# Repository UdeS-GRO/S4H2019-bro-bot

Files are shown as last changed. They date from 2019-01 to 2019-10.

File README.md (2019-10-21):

# bro-bot
<pre>
 ______     ______     ______     ______     ______     ______  
/\  == \   /\  == \   /\  __ \   /\  == \   /\  __ \   /\__  _\ 
\ \  __<   \ \  __<   \ \ \/\ \  \ \  __<   \ \ \/\ \  \/_/\ \/ 
 \ \_____\  \ \_\ \_\  \ \_____\  \ \_____\  \ \_____\    \ \_\ 
  \/_____/   \/_/ /_/   \/_____/   \/_____/   \/_____/     \/_/ 
 </pre>
Welcome to our college robotic project. We are the Bro-bot team and for a our session project we had to make an open source robotic project.

The Bro-Bot is a 3 degrees of freedom robot arm with a gripper at its end. The robot has 3 different control sytems: joint-directly controlled, cartesian teach controlled and impedance controlled. The grimper, on the other hand, is controlled by a wireless glove with flex sensors (inspired by a youtube project https://www.youtube.com/watch?v=uEd2B7fS8Eg&t=777s).

The team: 
We are at Université de Sherbrooke in the robotic engineering program. The team is composed of Tristan Dumais, Philippe Doucerain, Jean-Michel Lemaire, Maxime Lamoureux, Marc-André Martel and Étienne Villemure

## Start the project 
All materials to be acquired and all the necessary softwares to download can be found in this Github wiki in the section **Getting started!!**

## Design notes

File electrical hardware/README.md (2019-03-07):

# Electrical hardware

This section contains all the circuits in the project (except commercial PCB),

Some circuits is in a .fzz format. You will need to install the free sofware **Fritzing** to read/edit it. The installation procedure can be found in the [Wiki section](https://github.com/tdumais23/bro-bot/wiki/Getting-Started!).

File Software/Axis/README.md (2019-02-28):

# Axis class

The axis class contains all the necessary methods and attributes to use each dynamixel motors.

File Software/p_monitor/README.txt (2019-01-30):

The library p_monitor.h is a derived version of the p_monitor OpenCr example in the arduino IDE. You should read the p_monitor.cpp before 
using it to be aware of its license. 

This library is used to symplify the way of sending commands to the Dynamixel motors. If you want to use our main_opencr program, you
should copy this directory inside your /Arduino/libraries. In Windows it should be in C:\Users\user\Documents\Arduino\libraries.

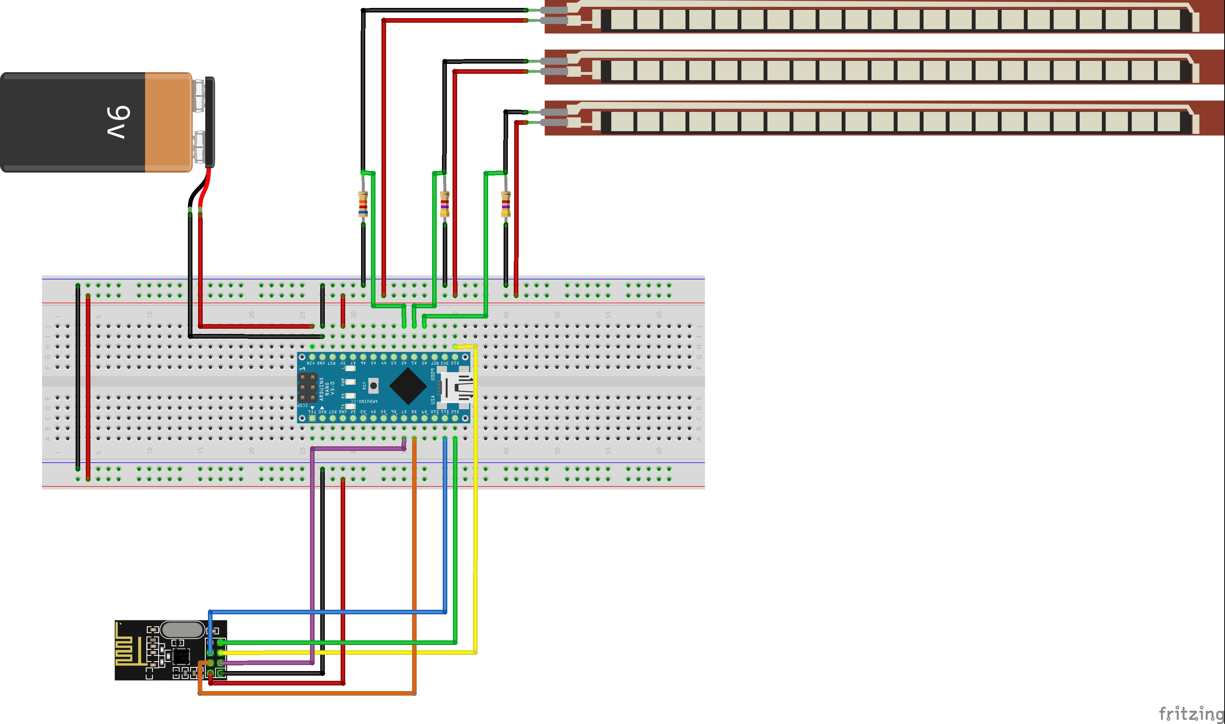
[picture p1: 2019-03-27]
electrical hardware/transceiver_gloveV2_bb.jpg

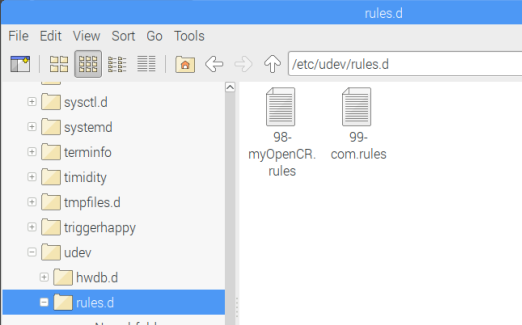
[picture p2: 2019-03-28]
finalUdevPicture.PNG

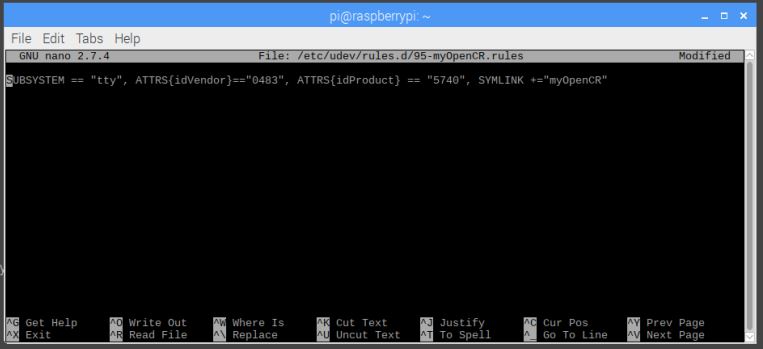
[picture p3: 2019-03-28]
UdevWiki.JPG

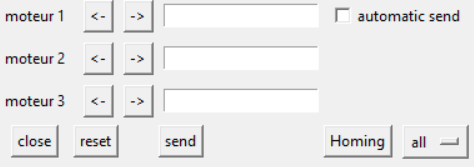
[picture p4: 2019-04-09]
image_wiki/moteur_control.PNG

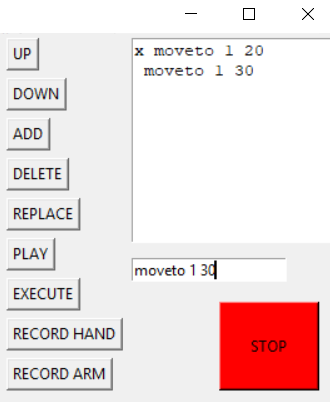
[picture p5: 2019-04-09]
image_wiki/add_commande.PNG

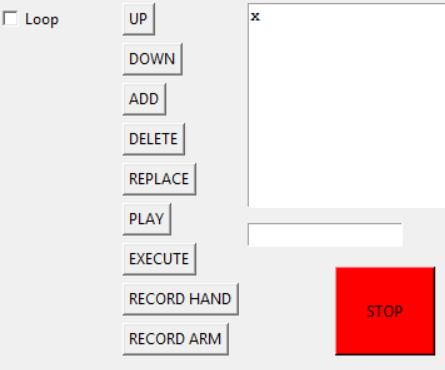
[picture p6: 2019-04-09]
image_wiki/routine_entry.PNG

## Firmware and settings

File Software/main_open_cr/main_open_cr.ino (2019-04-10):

/*
 This Source Code Form is subject to the terms of the Mozilla Public
 License, v. 2.0. If a copy of the MPL was not distributed with this
 file, You can obtain one at http://mozilla.org/MPL/2.0/.
*/

#include <DynamixelWorkbench.h>
//#include "p_monitor.h"  // À EFFACER LORSQUE LES TESTS SERONT TERMINÉS
#include "Axis.h"
#include "HandControl.h"
#include "Glove.h"


#if defined(__OPENCM904__)
  #define DEVICE_NAME "3" //Dynamixel on Serial3(USART3)  <-OpenCM 485EXP
#elif defined(__OPENCR__)
  #define DEVICE_NAME ""
#endif

//Constant declarations and definitions
#define TORQUE_COUNTER_REFERENCE  0
#define TORQUE_MAX_DIFFERENCE     40
#define TORQUE_CNT_BEFORE_TRIGGER 100
#define MOVING_CNT_BEFORE_TRIGGER 100
#define NUMBER_OF_AXIS            4   //+ 1 because there is no axis 0
#define NUMBER_OF_FINGERS         3

#define FINGER1_PIN               A0

//Global variables
String cmd[64]={"begin","57600"};
String cmd_tx[20];                //String to send to the motor after computing

HandControl *hand_control;

Axis *Axis_table[NUMBER_OF_AXIS];



// Hard Limit Switches inputs declaration
int inMinLS01 = 5;
int inMaxLS01 = 6;
int inMinLS02 = 7;
int inMaxLS02 = 8;
int inMinLS03 = 9;
int inMaxLS03 = 10;

// Limit Switches input status
bool MinLS[NUMBER_OF_AXIS];
bool MaxLS[NUMBER_OF_AXIS];


// Function declarations
void read_serial(void);
void torque_control(Axis * axis);
void fix_com(void);
void ack_msg(void);
void change_finger_control_mode(String new_mode);
void finger_control(int finger_number);
void stopBySwitch(Axis * axis);
void limitSwitch(void);
void split(String data, char separator, String* temp);
void glove_check(void);

// Initialisation
void setup()
{
    // Initialisation
    Serial.begin(57600);
    while(!Serial);     // Wait until the serial is ready
    
    //fix_com();    // fait bugger le opencr

    hand_control = new HandControl(NUMBER_OF_FINGERS);

    
    /* Axis creation*/
    Axis_table[0] = NULL; //There is no axis 0
    Axis_table[1] = new Axis(1,57600,250,0,359); 
    Axis_table[2] = new Axis(2,57600,350,5,225);
    Axis_table[3] = new Axis(3,57600,250);
    
    /*Init for the torque control*/
    Axis_table[1]->setTorqueFilter(TORQUE_COUNTER_REFERENCE,TORQUE_MAX_DIFFERENCE,TORQUE_CNT_BEFORE_TRIGGER);  
    Axis_table[1]->setMovingFilter(0, 0,MOVING_CNT_BEFORE_TRIGGER);
//test JM
    
    Axis_table[2]->setTorqueFilter(TORQUE_COUNTER_REFERENCE,TORQUE_MAX_DIFFERENCE+30,TORQUE_CNT_BEFORE_TRIGGER);  
    Axis_table[2]->setMovingFilter(0, 0,MOVING_CNT_BEFORE_TRIGGER);
    
    Axis_table[3]->setTorqueFilter(TORQUE_COUNTER_REFERENCE,TORQUE_MAX_DIFFERENCE,TORQUE_CNT_BEFORE_TRIGGER);  
    Axis_table[3]->setMovingFilter(0, 0,MOVING_CNT_BEFORE_TRIGGER);

    // Pinout Attribution for Limit Swtiches
    pinMode(inMinLS01, INPUT);
    pinMode(inMaxLS01, INPUT);
    pinMode(inMinLS02, INPUT);
    pinMode(inMaxLS02, INPUT);
    pinMode(inMinLS03, INPUT);
    pinMode(inMaxLS03, INPUT);

    
    
}

void loop() 
{
  short axis_index;

  // update all the status of the motors
  /*Axis_table[1]->readStatus();
  Axis_table[2]->readStatus();
  Axis_table[3]->readStatus();*/
    
  // Limits Switch digital Read
  limitSwitch();                          //test JM      
  
  //Read message
  read_serial();                          //test JM
  
  glove_check();
  
  //======Computing======
  
  // Torque control and verif if goal achieve of the moveTo
  for (axis_index =1; axis_index < NUMBER_OF_AXIS ; axis_index++)
  {
    Axis_table[axis_index]->verifGoalAchieve(); // faire un mode debug      //test JM
    torque_control(Axis_table[axis_index]);
  }

  // Finger control
  int finger_index;
  for (finger_index =1; finger_index <= NUMBER_OF_FINGERS; finger_index++)    //test jm
  {
    finger_control(finger_index);
  }
  
  // Moveto control
  /*for (axis_index =1; axis_index < NUMBER_OF_AXIS ; axis_index++)
  {
    torque_control(Axis_table[axis_index]);
  }*/
}

/* Stop the motor when it's called. This function is called in limitSwitch function
 * 
 * @param which axis is concerned
 * @return nothing
 */
void stopBySwitch(Axis * axis)
{
  axis->stopCmd();
}
/* This function turn off the torque when someone want to move the robot arm, it turns it back on when the robot stop to move.
 * It detects when the torque is anormally high as someone is pushing on it, and count to a certain number to verify if it's not only a
 * small collision. When the count is done, it's at that moment the torque turn off and turn back on after an other count which starts when the arm stop moving
 * 
 * @param which axis is concerned
 * @return nothing
 */
void torque_control(Axis * axis)
{
  if (axis->torqueControlEnable ==true)
  {
    short present_load = (short)axis->getTorque();  //COnvert to char to have negative value
    float present_load_f = (float)present_load;     //Convert to float
    float present_moving = (float)(1-axis->getMovingStatus());
    bool triggered =false;
    if(axis->isFreeToMove == false)
    {
      /*Verify if something tries to force against the motor */
     triggered = axis->torque_counter_filter->compute(present_load_f);        //test#0
     //Serial.print("Torque_cnt: ");                                          //test: counter
     //Serial.println(present_load_f);
     //Serial.println(axis->torque_counter_filter->counter);
      if(triggered)
      {
        axis->moving_counter_filter->reset_counter();
        axis->Disable();
        /*cmd_tx[0] = String("torque_off");                                                   //TODO : Implementer un système de queue de message 
        cmd_tx[1] = String(axis->ID);
        dynamixel_command(cmd_tx); */
        axis->isFreeToMove = true;
        axis->blink(GREEN_BLINK,500);   //Blink 500 ms
      }
    }
    else 
    { 
      /*Verify if something/someone is still moving the motor*/   
      triggered = axis->moving_counter_filter->compute(present_moving);
//      Serial.print("Moving_cnt: ");                                          //test: counter
//      Serial.println(axis->moving_counter_filter->counter);  
      axis->blink(GREEN_BLINK,500);   //Blink 500 ms
      
      if(triggered)
      {
        /*cmd_tx[0] = String("torque_on");
        cmd_tx[1] = String(axis->ID); 
        dynamixel_command(cmd_tx);*/
        axis->Enable();
        axis->torque_counter_filter->reset_counter();
        
        axis->isFreeToMove = false;

        
        axis->blink(STOP_BLINK,500);   //Blink 500 ms
      }
    }
  }
  else if (axis->isFreeToMove == true)
  {
    axis->isFreeToMove = false;
    axis->torque_counter_filter->reset_counter();
    axis->moving_counter_filter->reset_counter();
    axis->blink(STOP_BLINK,500);   //Blink 500 ms
    
    /*cmd_tx[0] = String("torque_on");
    cmd_tx[1] = String(axis->ID); 
    dynamixel_command(cmd_tx);*/
    axis->Enable();
  }
}

/*  This function read the command that comes from the serial monitor or the python interface. Depending of the cmd send by the user, it calls the
 *  function related to it. 
 * 
 * @param nothing
 * @return nothing
 */
void read_serial(void)
{
    if(Serial.available())
    {
      String read_string = Serial.readStringUntil('\n');
      read_string.trim();    
      split(read_string, ' ', cmd);   

      Axis* axis;
      /* Is the motor available */
      if ((cmd[1].toInt()  >= 1)  && (cmd[1].toInt()  < NUMBER_OF_AXIS))
      {
        /* Select the right motor to talk to*/
        int ID = cmd[1].toInt();
        
        axis = Axis_table[ID];
      
       
         if(cmd[0] == "zero")       // Homing
         {
            axis->HomeRequest(&MinLS[ID]);
         }
         
        else if(cmd[0] == "speed")  //  send a velocity to the motor
         {
            axis->moveAtSpeed(cmd[2]);
         }
         
        else if(cmd[0] == "rd")    // to read a Register of the motor 
         {
            axis->readRegister(cmd[2]);
         }
        else if(cmd[0] == "wr")     // write in the register of the motor
         {
            axis->writeRegister(cmd[1],cmd[2].toInt());
         }
        else if(cmd[0] == "Pos")    // know the actual position of the motor
         {
            Serial.print(axis->getPosition());
         }
        else if(cmd[0] == "Move")   // Know if the motor is presently moving
         {
            axis->getMovingStatus();
         }
        else if(cmd[0] == "Cur")  // Know the actual Current of the motor [1 unit = 2.69 [mA] ]
         {
            axis->getCurrent();
         }
        else if(cmd[0] == "Torq") // Know the actual torque of the motor [1 unit = 2.69 [mA] ]
         {
            axis->getTorque();
         }
        else if(cmd[0] == "Vel") // Know the actual velocity of the motor[ 1 unity is 0.229 rpm ]
         {
            Serial.println(axis->getVelocity());
         }
         else if (cmd[0] == "stop") // stop each motor 
          {
            short axis_index;
             // Set the motor velocity to 0 and indicates that it has reach is position
            for (axis_index =1; axis_index < NUMBER_OF_AXIS ; axis_index++)
              {
                Axis_table[axis_index]->stopCmd();
              } 
          }
        else if(cmd[0] == "moveto") // move a motor to a certain angle (degrees)
         {
            axis->Moveto(cmd[2].toFloat());
         }
        else if (cmd[0] == "torque_control_enable") // to use the torque control mode
        {
          axis->torqueControlEnable = true;
          Serial.println(String( "Torque control enable: " + String(ID))); 
        }
        else if (cmd[0] == "torque_control_disable") // ignore the torque control mode
        {
          axis->torqueControlEnable = false;
        }
      }
      
      /* Message not destined to motors */
      /* Finger control message */
      if (cmd[0] == "finger_mode")                  // change the finger mode
      {
          change_finger_control_mode(cmd[1]);
      }
      else if (cmd[0] == "finger_move")            // to move a finger to a certain place
      {
        /* Read the PWM value from gui for a specific finger */
        hand_control->setFingerGuiValue(cmd[1].toInt(),cmd[2].toInt());
        
      }
            else if (cmd[0] == "stop")
      {
        short axis_index;
         // Set the motor velocity to 0 and indicates that it has reach is position
        for (axis_index =1; axis_index < NUMBER_OF_AXIS ; axis_index++)
        {
          Axis_table[axis_index]->stopCmd();
        } 
      }
      else if (cmd[0] == "record_arm")
      {
        int value_to_send = 0;
        String str_to_send = "";
        short axis_index;     
           
        for (axis_index =1; axis_index < NUMBER_OF_AXIS ; axis_index++)
        {
            str_to_send = String("recorded_arm " + String(axis_index));
            value_to_send = Axis_table[axis_index]->getPosition();
            Serial.println(String(str_to_send + " " + String(value_to_send)));
        }
      }
      else if (cmd[0] == "record_hand")
      {
        int value_to_send = 0;
        String str_to_send = "";
        short axis_index;     
           
        for (axis_index =1; axis_index <= NUMBER_OF_FINGERS ; axis_index++)
        {
              // Add the read of servo 
//            str_to_send = String("recorded_hand " + String(axis_index));
//            value_to_send = Axis_table[axis_index]->getPosition();
//            Serial.println(String(str_to_send + " " + String(value_to_send)));
        }  
      }
  }
}
/**
* This function change the mode in which the finger_control is. 4 modes are avaible
* LOCK, FREE, GUI, GLOVE
* 
* @param mode we want
* @return Nothing.
*/
void change_finger_control_mode(String new_mode)
{
  bool doModeExist =false;
  int mode_debug;
  
  if(new_mode == "LOCK")
  {
    hand_control->setMode(LOCK);
    doModeExist = true;
  }
  else if(new_mode == "FREE")
  {
    hand_control->setMode(FREE);
    doModeExist = true;
  }
  else if(new_mode == "GUI")
  {
    hand_control->setMode(GUI);
    doModeExist = true;
  }
  else if(new_mode == "GLOVE")
  {
    hand_control->setMode(GLOVE);
    doModeExist = true;
  }
  else
  {/* NOP */}

  if (doModeExist)
  {
    Serial.print(String("New finger control mode: " + new_mode));
    Serial.println(String( ": " + String(hand_control->getMode())));
  }
}

/*void fix_com(void)      VOIR SI FONCTIONNE BIEN SANS CETTE FONCTION. SI OUI ON L'EFFACE
{
    cmd_tx[0] = String("begin");    //Bug qui doit être régler
    cmd_tx[1] = String("57600"); 
    dynamixel_command(cmd_tx);
    cmd_tx[0] = String("scan");
    cmd_tx[1] = String("3"); 
    dynamixel_command(cmd_tx);
}*/



/**
* This function control the finger depending of the mode it is in. If it's in Glove mode, the command are coming from the Glove by instance
* 
* @param which finger is concern
* @return Nothing.
*/
void finger_control(int finger_number)
{
  int new_PWM_cmd =0;
  if( hand_control->getMode() == LOCK)
  {
    hand_control->getMotorValue();
    hand_control->setMotorValue();
    /* do nothing and keep last position */
  }
  else if (hand_control->getMode() == FREE)
  {
    /* Set the PWM to 0 to disable the servo*/          //TODO :Add the pwm control
  }
    else if (hand_control->getMode() == GLOVE)
  {
    /* Read the commands sent by radio*/
    hand_control->setMotorValue();
    //new_PWM_cmd = hand_control->getFingerGloveValue(finger_number);
    //Serial.println(String("Radio:" +String(new_PWM_cmd)));       //TODO :Add the pwm control
  }
    else if (hand_control->getMode() == GUI)
  {
    /* Read the last command sent by the GUI*/
    hand_control->setMotorValue();
     //new_PWM_cmd = hand_control->getFingerGuiValue(finger_number);
     //Serial.println(String("GUI:" +String(new_PWM_cmd)));      //TODO :Add the pwm control
  }
}

/**
* This function detects if a limit switch is on. When it is, it stops the motor and forbid it to go in the direcetion it was going 
* until it moves the other side
* 
* @param Nothin
* @return Nothing.
*/
void limitSwitch(void)
{
  // Limits Switch digital Read
  MinLS[1] = digitalRead(inMinLS01);
  MinLS[2] = digitalRead(inMinLS02);
  MinLS[3] = digitalRead(inMinLS03);
  MaxLS[1] = digitalRead(inMaxLS01);
  MaxLS[2] = digitalRead(inMaxLS02);
  MaxLS[3] = digitalRead(inMaxLS03);  // decommenter lorsque les pins seront utilises. Sinon ce sont des valeurs randoms qui sont donnes
  // stoping by limit switch
  
int axis_index;

for (axis_index =1; axis_index < NUMBER_OF_AXIS ; axis_index++)
  {
    if(Axis_table[axis_index]->getSwitchMin() || Axis_table[axis_index]->getSwitchMax())
    {
        if(!MinLS[axis_index])
        {
          Axis_table[axis_index]->setSwitchMin(false);
        }
        if(!MaxLS[axis_index])
        {
          Axis_table[axis_index]->setSwitchMax(false);
        }
    }
    else if((!Axis_table[axis_index]->getSwitchMin())&&(!Axis_table[axis_index]->getSwitchMax())) // à changer avec le SwitchMode dans axis.cpp
    {
      if ((MinLS[axis_index] && Axis_table[axis_index]->Sts_Homing == 0 ) || (MaxLS[axis_index] && Axis_table[axis_index]->Sts_Homing == 0))
      {
        
        //stopBySwitch(Axis_table[axis_index]);
        Axis_table[axis_index]->Disable();
        if(Axis_table[axis_index]->getJMWatchdog())
        {
          Axis_table[axis_index]->ack_msg();
        }
             
        if (MinLS[axis_index])
          {
            Serial.print("switch MIN ");
            Serial.println(axis_index);
            Axis_table[axis_index]->setSwitchMin(true);        
            Axis_table[axis_index]->setPermissionBackward();
          }
        else if (MaxLS[axis_index])
          {
           Serial.print("switch MAX ");
           Serial.println(axis_index);
           Axis_table[axis_index]->setSwitchMax(true);  
           Axis_table[axis_index]->setPermissionForward();
          }
        else 
          {
            Serial.println("WHAAT IS HAPPENING HERE");
          }
      }
     else if (Axis_table[axis_index]->Sts_Homing == 1)
     {
       Axis_table[axis_index]->HomeRequest(&MinLS[axis_index]);
     }
    }

// Juste pour faire des tests
  /*if (MinLS[1] && Axis_table[1]->Sts_Homing == 0)  // *************** Le test est pour le moteur 3 *************************
  { 
    //Serial.println("Wouhou! it is working !!");
    stopBySwitch(Axis_table[1]);
    Axis_table[1]->setPermissionForward();
  }

  
  if( Axis_table[1]->Sts_Homing == 1)
  {
   Axis_table[1]->HomeRequest(&MinLS[1]);
  }*/

  }
}

/**
* this function read a string and put every word separate by a space in a list. We use it to receive the commands
* in readSerial()
* 
* @param data to read, what is used to detect where to separate the date, which list to put the separate data in
* @return Nothing.
*/
void split(String data, char separator, String* temp)
{
  int cnt = 0;
  int get_index = 0;

  String copy = data;
  
  while(true)
  {
    get_index = copy.indexOf(separator);

    if(-1 != get_index)
    {
      temp[cnt] = copy.substring(0, get_index);

      copy = copy.substring(get_index + 1);
    }
    else
    {
      temp[cnt] = copy.substring(0, copy.length());
      break;
    }
    ++cnt;
  }
}

/**
* this function read a string and put every word separate by a space in a list. We use it to receive the commands
* in readSerial()
* 
* @param data to read, what is used to detect where to separate the date, which list to put the separate data in
* @return Nothing.
*/
void glove_check(void){
//  if(hand_control->getMode()==GLOVE){
//    if(radio.available()){
//      hand_control->read_radio();
//    }
//  }
//  if(hand_control->getMode()!=FREE){
//    hand_control->attachMotor();
//  }
}

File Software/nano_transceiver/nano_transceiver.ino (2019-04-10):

/*
*  This Source Code Form is subject to the terms of the Mozilla Public
* License, v. 2.0.If a copy of the MPL was not distributed with this
* file, You can obtain one at http ://mozilla.org/MPL/2.0/.
*/
#include <SPI.h>
#include <nRF24L01.h>
#include <RF24.h>

#define THUMB_PIN A5
#define INDEX_PIN A7
#define MIDDLE_PIN A6
#define NB_MESSAGE 3
#define SIZE_MESSAGE_BUFFER 50

RF24 radio(7, 8); // CE, CSN

const byte address[6] = "gant0";

String message[NB_MESSAGE];
void read_sensor(void);
void send_message(void);
void motor_control(void);
float filter_signal(float signal_to_filter);
float old_finger_0 = 0;
float old_finger_1 = 0;
float old_finger_2 = 0;
float offset_finger = 2;
int fingerPins[3]={THUMB_PIN,INDEX_PIN,MIDDLE_PIN};
int CalibrationVals[2][3];   

void setup() {
  Serial.begin(9600);

  pinMode(THUMB_PIN, INPUT);
  pinMode(INDEX_PIN, INPUT);
  pinMode(MIDDLE_PIN, INPUT);
  CalibrateFlexSensors();
  radio.begin();
  radio.openWritingPipe(address);
  radio.setPALevel(RF24_PA_MAX);  // Lowest power
  radio.stopListening();          // Setting in transmiting mode
  float old_finger_0 = analogRead(THUMB_PIN);
  float old_finger_1 = analogRead(INDEX_PIN);
  float old_finger_2 = analogRead(MIDDLE_PIN);
  
}

void loop() 
{
  /* Read the sensors and build strings to send */
  read_sensor();
   
  /* Send the builded strings */
  send_message();
}
//float old_value=0;      // a enelever

//float filter_signal(int signal_to_filter, float filterFrequency){
  // filters out changes faster than specified freq.
  
  // create a one pole (RC) lowpass filter
//  FilterOnePole lowpassFilter( LOWPASS, filterFrequency );  
// float filtered_signal = lowpassFilter.input(signal_to_filter); 
  //old_value = 0.3*old_value + 0.3*((float)signal_to_filter);
  //float filtered_signal = old_value;
 // return filtered_signal;
  
//}

/*Calibrates de flex sensors by seting minimum average value when the hand is extended
 * and average maximum value when it is in fist position
 * 
 * @param Nothing
 * @return Nothing
 */
void CalibrateFlexSensors(){
  int calibrationCount=0;
  while(calibrationCount<=1){
    /* If calibrationCount==0, then find minimum flex value (hand relaxed position)
     * Elif calibrationCount==1, then find maximum flex value (hand in fist position)
     */
     if(calibrationCount==0){
      Serial.println("Please lay your hand flat");
      delay(3000);
      Serial.println("Collecting minimum flex readings");
     }
     else if(calibrationCount==1){
      Serial.println("Please close you hand into a fist");
      digitalWrite(LED_BUILTIN, HIGH);
      delay(3000);
      Serial.println("Collecting maximum flex readings");
     }
     for(int i=0; i<3; i++){
      int readingCount=0;
      int readingSum=0;
      while(readingCount<10){                        //Take 10 unique readings
        readingSum+=analogRead(fingerPins[i]);
        readingCount+=1;
        delay(200);
      }      
      CalibrationVals[calibrationCount][i]=readingSum/10;    //Record average of 10 readings
     }
     calibrationCount+=1;
  }
  Serial.println("Calibration Complete");
  digitalWrite(LED_BUILTIN, LOW);
  Serial.println("In the order from thumb to middle, your offsets are:");
  for(int i=0; i<2; i++){
    if(i==0){Serial.print("Minimum Offsets:\t");}
    else{Serial.print("Maximum Offsets:\t");}
    for(int j=0; j<3; j++){
      Serial.print(CalibrationVals[i][j]);
      Serial.print(", ");
    }  
    Serial.println();
  }
}
/* Read the flex sensors and translate it in a value of 0 to 20. so 1 unity is 19 degrees
 * Because the value can vary a little bit, there is an offset to exceed to change the value 
 *   
 * @param Nothing
 * @return Nothing 
 */
void read_sensor(void)
{ 
  //int finger_0 = lowpassFilter.input(analogRead(INDEX_PIN)); //Read voltage of the voltage divider of the index
  float finger_0 = analogRead(THUMB_PIN);
  //Serial.println("THUMB_PIN: " + String(finger_0) + "\n");
  //finger_0 = filter_signal(finger_0, 5000);    //filtrage du signal RC a la freq specifiee 
  finger_0 = map(finger_0, CalibrationVals[0][0], CalibrationVals[1][0], 0, 20);
  finger_0 = constrain(finger_0, 0, 20);
  
  if(finger_0 < old_finger_0 + offset_finger && finger_0 > old_finger_0 - offset_finger){
    finger_0 = old_finger_0;
  }
 
  else{
    old_finger_0 = finger_0;
  }
    
  float finger_1 = analogRead(INDEX_PIN);     //Read voltage of the voltage divider of the index
  //Serial.println("INDEX_PIN: " + String(finger_1) + "\n");
  //finger_1 = filter_signal(finger_1, 5000);    //filtrage du signal RC a la freq specifiee 
  finger_1 = map(finger_1, CalibrationVals[0][1], CalibrationVals[1][1], 0, 20);
  finger_1 = constrain(finger_1, 0, 20);
  
  if(finger_1 < old_finger_1 + offset_finger && finger_1 > old_finger_1 - offset_finger){
    finger_1 = old_finger_1;
  }
  else{
    old_finger_1 = finger_1;
  }
  
  float finger_2 = analogRead(MIDDLE_PIN);     //Read voltage of the voltage divider of the major
  //Serial.println("MIDDLE_PIN: " + String(finger_2) + "\n");
  //finger_2 = filter_signal(finger_2, 5000);    //filtrage du signal RC a la freq specifiee 
  finger_2 = map(finger_2, CalibrationVals[0][2], CalibrationVals[1][2], 0, 20);
  finger_2 = constrain(finger_2, 0, 20);
  
  if(finger_2 < old_finger_2 + offset_finger && finger_2 > old_finger_2 - offset_finger){
    finger_2 = old_finger_2;
  }
  else{
    old_finger_2 = finger_2;
  }
  /* Add message here and change the NB_MESSAGE to fit the number of strings below */
  message[0] = String(String(finger_0)+",");
  message[1] = String(String(finger_1)+",");
  message[2] = String(String(finger_2)+";"+" ");
  //Serial.print(message[0]+message[1]+message[2]);
  //message[3] = String("\n");
  //delay(1000);
}
/* This function send the value computed in the read_sensor function
 *  
 * @param which axis is concerned
 * @return nothing
 */
void send_message(void)
{
  int counter =0;
  char message_buff[SIZE_MESSAGE_BUFFER]="";

  message[0] = message[0]+message[1]+message[2];
  Serial.println(message[0]);
  /*for(counter=0; counter < NB_MESSAGE; counter++)
  {*/
    message[0].toCharArray(message_buff,message[0].length());
    radio.write(&message_buff, sizeof(message_buff));     // Send over the radio
    memset(message_buff, 0, sizeof(message_buff));        //Clear the buffer
  //}
}

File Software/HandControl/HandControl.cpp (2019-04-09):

/*
	This Source Code Form is subject to the terms of the Mozilla Public
	License, v. 2.0.If a copy of the MPL was not distributed with this
	file, You can obtain one at http ://mozilla.org/MPL/2.0/.
*/

#include "HandControl.h"

/**
* Constructor of the Handcontrol class
*
* Initialize the size of the finger data arrays and the mode to the FREE mode
*
* @param The number of fingers
* @return Nothing.
*/
HandControl::HandControl(int number_of_fingers)
{
	finger_gui_cmd_ = new int[number_of_fingers];
	finger_glove_cmd_ = new int[number_of_fingers];
	mode = FREE;
	nb_of_finger = number_of_fingers;
	thumb.attach(pin_m1);
  	INDEX.attach(pin_m2);
  	middle.attach(pin_m3);

	// Initialisation of glove communication
    	radio = new RF24(7, 8); // CE, CSN
    	const byte address[6] = "gant0";
    	radio->begin();
    	radio->openReadingPipe(0, address);
    	radio->setPALevel(RF24_PA_MIN);
    	radio->startListening();

	int index;
	for (index = 0; index < number_of_fingers; index++)
	{
		finger_gui_cmd_[index] = 0;
		finger_glove_cmd_[index] = 0;
	}
}


HandControl::~HandControl()
{
	delete[] finger_gui_cmd_;
	delete[] finger_glove_cmd_;
}

/**
* Set the mode in wich the hand will be controlled.
*
* @param The new mode.
* @return Nothing.
*/
void HandControl::setMode(ControlFingerState new_mode)
{
	mode = new_mode;
}

/**
* Get the actual mode in wich the hand is controlled.
*
* @param Nothing.
* @return Actual mode.
*/
ControlFingerState HandControl::getMode(void)
{
	return mode;
}

/**
* Set the value of the PWM to send to a finger by the GUI.
*
* The specified value of PWM will be send inside in a private specific array.
* The array index is the finger number -1.
*
* @param The number of the finger (index-1) and the new value to insert.
* @return Nothing.
*/
void HandControl::setFingerGuiValue(int finger_number, int new_value)
{
	if ((finger_number > 0) && (finger_number <= nb_of_finger))
	{
		finger_gui_cmd_[finger_number - 1] = new_value;
	}
}

/**
* Get the value of the PWM for a specific motor received from the GUI.
*
*
* @param The number of the finger (index-1)
* @return The PWM value of the corresponding finger.
*/
int HandControl::getFingerGuiValue(int finger_number)
{
	if ((finger_number > 0) && (finger_number <= nb_of_finger))
	{
		return finger_gui_cmd_[finger_number - 1];
	}
}

/**
* Set the value of the PWM to send to a finger by the Glove.
*
* The specified value of PWM will be send inside in a private specific array.
* The array index is the finger number -1.
*
* @param The number of the finger (index-1) and the new value to insert.
* @return Nothing.
*/
void HandControl::setFingerGloveValue(int finger_number, int new_value)
{
	if ((finger_number > 0) && (finger_number <= nb_of_finger))
	{
		finger_glove_cmd_[finger_number - 1] = new_value;
	}
}

/**
* Get the value of the actual position of a specified finger
*
* @param The number of the finger (index-1)
* @return The PWM value of the corresponding finger.
*/
int HandControl::getFingerGloveValue(int finger_number)
{
	if ((finger_number > 0) && (finger_number <= nb_of_finger))
	{
		return finger_glove_cmd_[finger_number - 1];
	}
}

/**
* Get the value of the actual position of each servos 
*
* @param The new mode.
* @return Nothing.
*/
void HandControl::getMotorValue(void)
{
	//read servos angle
	finger_glove_cmd_[0] = thumb.read();             
	finger_glove_cmd_[1] = INDEX.read();
	finger_glove_cmd_[2] = middle.read();
}

/**
* send the commands to the servos related to the fingers
*
* @param The new mode.
* @return Nothing.
*/
void HandControl::setMotorValue(void)
{
	//move servos to set angles
	thumb.write(finger_glove_cmd_[0]);             
	INDEX.write(finger_glove_cmd_[1]);
	middle.write(finger_glove_cmd_[2]);
}

/**
* translate the command receive by the radio to work with the servos. 
*
*
* @param The new mode.
* @return Nothing.
*/
void HandControl::read_radio(void)
{
  radio->read(&text_radio, sizeof(text_radio));
  Serial.println("je suis dans read_radio");
  int i = 0;
  int finger_id = 0;

  for(i=0;text_radio[i]!=';';i++){
    finger_value_str += text_radio[i];
    if(text_radio[i]==','){
      finger_glove_cmd_[finger_id] = finger_value_str.toInt();
      finger_id += 1;
      finger_value_str = "";
    }
  }
}

/**
* detach the srevos related to each fingers.
* Used when it is in Free mode
*
*
* @param The new mode.
* @return Nothing.
*/
void HandControl::detachMotor(void)
{
	thumb.detach();
  	INDEX.detach();
  	middle.detach();
}

/**
* Attach a servo for each finger 
*
* @param The new mode.
* @return Nothing.
*/
void HandControl::attachMotor(void)
{
	thumb.attach(pin_m1);
  	INDEX.attach(pin_m2);
  	middle.attach(pin_m3);
}

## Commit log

2019-01-23 ajout de la librairie dynamixelWorkBench
2019-01-23 read/write for arduino and pi
2019-01-23 retrait du dossier test et de son contenu
2019-01-23 AJout de de p_monitor sous forme de librarie et ajout de librarie de WString.h dans le package. Non-testé
2019-01-23 Ajout d'un pointeur de la librairie de p_monitor dans le DynamixelWorkbenchl. Non testé
2019-01-23 Librairies de monitor testé
2019-01-29 Rajout d'un main du openCr et mettre à l'externe la librarie de pmonitor
2019-01-29 Supression du dynamixel_workbench car la librarie p_monitor ni s'y retrouve plus et le package est redevenu comme avant. J'ai tout de même garder un backup du dossier sur mon ordi au cas où
2019-01-29 Changement du path du include monitor.p, car la librairie p_monitor.h n'était plus accessible
2019-01-29 Changement du path du include p_monitor.h
    Le path n'accédait plus la librairie
2019-01-30 Intégration de la license dans le main du OpenCr
2019-01-30 read write function with thread
2019-01-30 Project license
    Tristan enlève pas la licence
2019-02-06 modification code Arduino
2019-02-20 add play and execute button
2019-02-21 nrf24l01 libraries and code for the transmiter(glove) and receiver(arduino)
    [transceiver_glove.fzz]
2019-02-22 Implémentation du contrôle de torque (modification classe Axis, main OpenCr et ajout de la librairies counter_filter). Pas testé et bloqué par des éléments de Axis
2019-02-22 Rajout d'un blink lorsque le moteur est contrôlé par un torque qui lui ait appliqué
2019-02-25 Axix .cpp -Modification du constructeur pour indiquer le modèle du moteur -Commenter les fonctions d'affichage (necessiterait un mode verbose) - Modification du get_torque pour qu'il s'adapte au mode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
    counter_filter
    - Fix d'un bug car il manquait un return dans la fonction
    - L'attribut counter est rendu public
    Main open cr
    - Modification des paramètres pour les filtres (testé avec 250 seulement)
    - Rajout de la fonction torque_control
    - Rajout d'un buffer de conversion float -> short -> float
    -Rajout de fix com car il n,est pas possible de renvoyer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
    [Axis.cpp, main_open_cr.ino]
2019-02-25 -Serial read peut lire des messages pour les trois moteurs selon le protocol suivant : "command ID donnée"
    -Les axes se retrouvent dans un tableau de pointeur d'"axis"
    - Nouveaux messages "torque_control_enable ID" et "torque_control_disable ID"
2019-02-28 Code de la démo:
    Ajustement des soft limits et des contrôles des soft limits
2019-03-03 Move the electrical schematic into a new directory
    [transceiver_glove.fzz]
2019-03-07 Remove dependancy between counter_filter and Arduino.h
2019-03-07 interface modifié pour thread
2019-03-10 All motor buttons unit test
2019-03-10 Test for all angle/motors button function
2019-03-10 calibration and main for flex sensor
2019-03-10 AJout Fonction homing pour les axes
2019-03-10 Lecture des digital I/O dans le main
2019-03-11 Add a setup function to reset all values and added the delete test
    [interface_pi.py, test_interface_pi.py]
2019-03-11 electrical schematic glove
    [transceiver_gloveV2.fzz]
2019-03-12 Ajout des test d'envoie de routine, bloquer par le test de la loop
2019-03-13 Communication entre gant et arduino mega 2560
    Communication entre gant et arduino mega 2560 fonctionnel.
    Il reste a tester sur le openCR.
    Le voltage converti par le ADC est maintenant filtré par variation d'amplitude.
    Il reste a tester avec un moteur pour tester le lag et que tout fonctionne.
2019-03-13 Ajout de la fonction Stop lorsque on touche un Limit Switch, Ajout de la fonction homing dans le main à la place de l'ancienne fonction zero
2019-03-13 Ajout de la fonction stopCmd, modification de la fonction HomeRequest
2019-03-13 fonction homing
2019-03-13 Motors control added
    The control of one of the fingers is working.
    We now need to implement the other fingers.
2019-03-20 Ajout des tests pour les fonctions de controls de doigts ajout des fonctions de controle de doigts, rajouter un flag 'test' pour pouvoir se mettre dans un envrionnement sans port série impliquer
2019-03-20 Ajout des licenses à tous les codes
2019-03-20 Main read finger control mode from python
2019-03-20 Torque control marche. Création de la classe HandControl pour controler les doigts
2019-03-20 update glove 3 finger
    [transceiver_gloveV2.fzz]
2019-03-20 Ajout de la réception des changements de mode pour le gant. Création de la librairie HandControl pour les dogits
2019-03-24 Ajout d'une protection contre le control de doigts inexistant et et ajustement de la lecture des commmandes pour le control des doigts
2019-03-24 Ajout des déclarations de fonctions pour le bouton stop dans le python et l'openCr
2019-03-26 Added the docstring to each function of pi_interface.pi. Add the stop button on the interface
2019-03-27 switch and moveto without while tested
2019-03-27 Importation de Moveto dans la classe, clarrification de certain tags. Optimisation de la classe.
2019-03-28 Ajout de la calibration au demarrage du gant
    Au demarrage, garder la main ouverte pour mapper la position minimum, lorsque la LED L s'allume, fermer le poing pour la position max. Une fois que la LED s'est éteinte, la calibration est terminée.
2019-04-06 reglage de bugs moteur
    [main_open_cr.ino]
2019-04-07 droplist and homing button add to interface and limitSwitch improved by adding a switchMode in axis
2019-04-08 rajout du controle de la main au mainopenCR
2019-04-09 Fix exit issues and repositionned the loop checkbox
    [interface_pi.py]
2019-04-09 Update the maximum value of the finger slider from 200 to 180 to match the command sent by the glove
2019-04-09 appel dynamique de handcontrol plutot que statique
2019-04-10 Ajout du CAD complet du robot et ajout de la classe test de Axis
